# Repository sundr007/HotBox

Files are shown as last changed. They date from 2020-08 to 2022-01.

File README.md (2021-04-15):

# HotBox


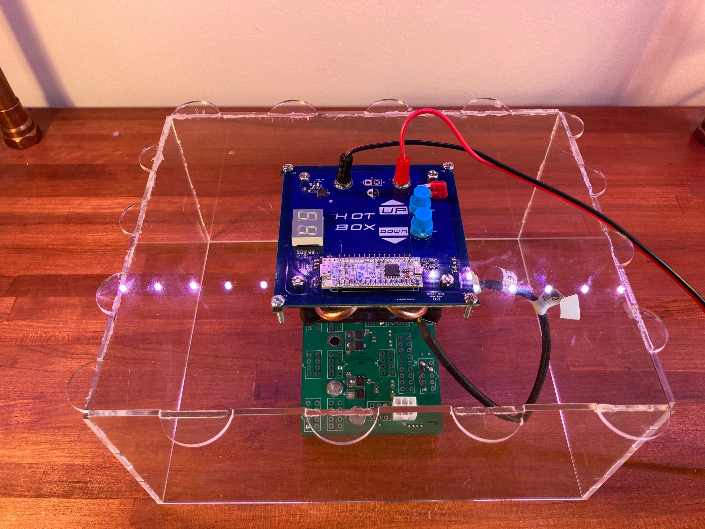
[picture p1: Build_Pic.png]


I use this when I'm testing electronics on my benchtop.  I put this box on top of what I'm testing to raise the ambient temperature.  This is convenient because I can leave my probes and other wires hooked up as is.
This box can raise the ambient temperature up to 55C.

The design consists of a finger edge laser cut acrylic box that has a circuit board assembly mount in the top center of it.  I put foam on the bottom edge of the box so it can nicely sit on top of wires and cables without air gaps.  

The circuit board assembly consists of a 2 layer PCB meant to fit PCBWAY's cheap board special (hint,they're $1 a piece for QTY 5).  On the PCB there is a ST NUCLEO-G431KB board which is an easy way to add a microcontroller.  There's 2 buttons to control temperature setpoint, a 7 segment display to display temperature, a peltier plate that acts as the heating element, and an Intel LGA1155 processor fan to spread the heat from the peltier plate.

I have built the current revision and found that it works as expected and I'm able to use it as I debug and test my electronics.

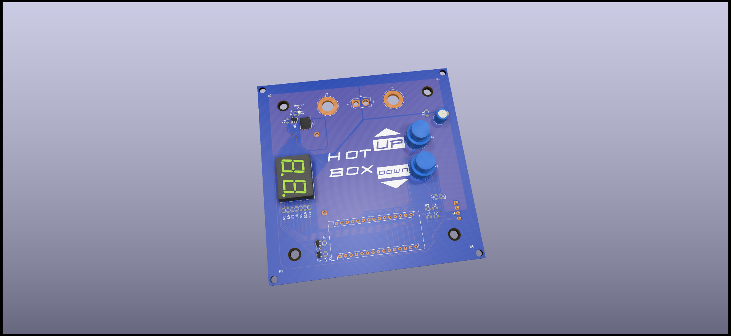
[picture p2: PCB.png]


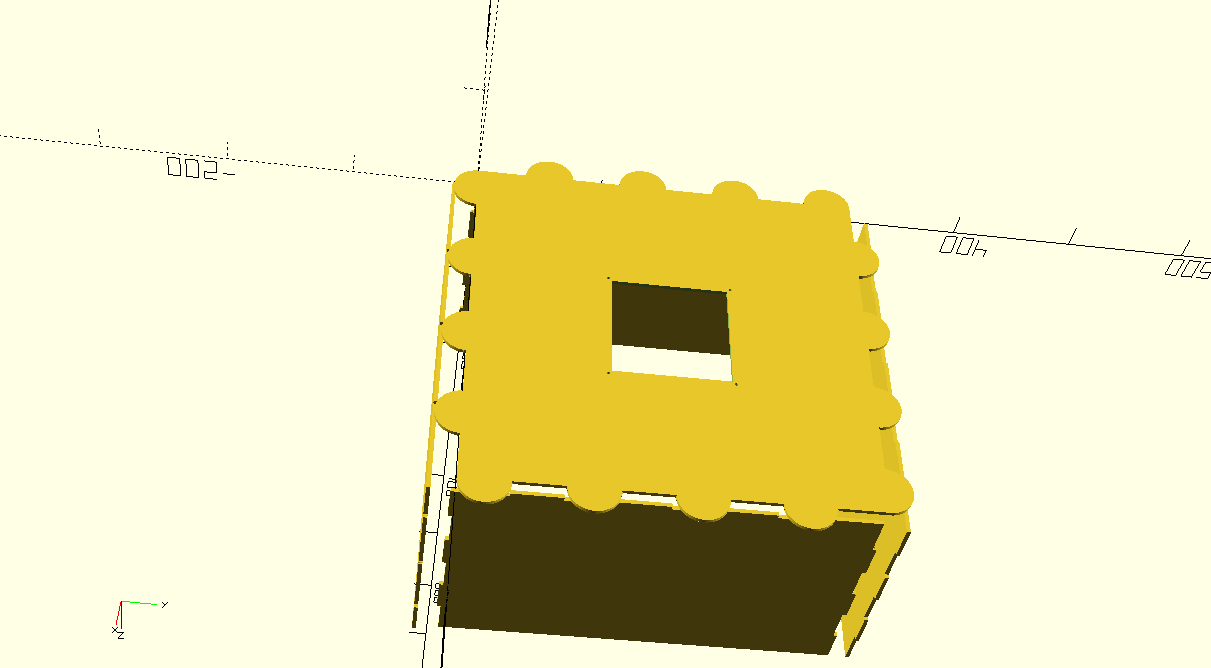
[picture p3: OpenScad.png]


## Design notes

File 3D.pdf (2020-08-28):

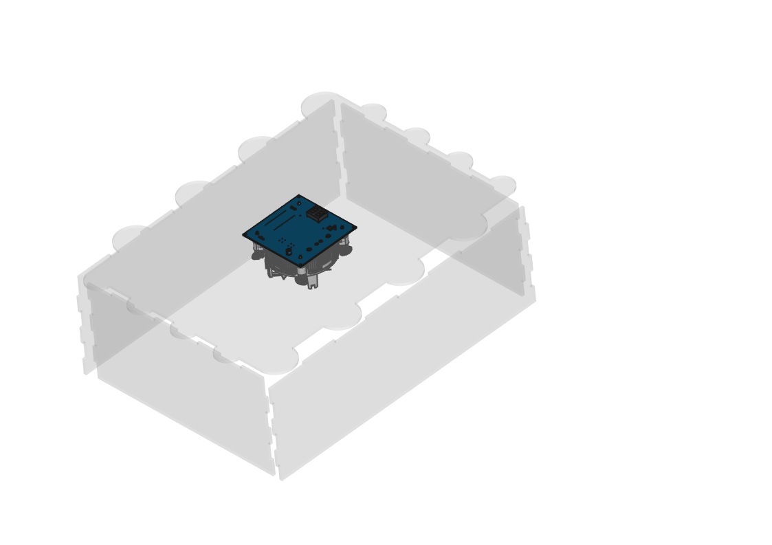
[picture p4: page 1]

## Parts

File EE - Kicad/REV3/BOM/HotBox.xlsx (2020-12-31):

Prj: | HotBox.xml |  |  |  | Board Qty: | 100
Co.: |  |  |  |  | Unit Cost: | $0.00
Prj date: | Mon 23 Nov 2020 11:21:40 PM CST |  |  |  | Total Cost: | $0.00 |  |  |  | $0.00 | 0 |  |  |  | $0.00 | 0 |  |  |  | $0.00 | 0 |  |  |  | $0.00 | 0 |  |  |  | $0.00 | 0 |  |  |  | $0.00 | 0 |  |  |  | $0.00 | 0 |  |  |  | $0.00 | 0
$ date: | 2020-11-23 23:21:47
Global Part Info |  |  |  |  |  |  | Arrow |  |  |  |  | Digi-Key |  |  |  |  | Farnell |  |  |  |  | LCSC |  |  |  |  | Mouser |  |  |  |  | Newark |  |  |  |  | RS Components |  |  |  |  | TME
Refs | Value | Footprint | Manf# | Qty | Unit$ | Ext$ | Avail | Purch | Unit$ | Ext$ | Cat# | Avail | Purch | Unit$ | Ext$ | Cat# | Avail | Purch | Unit$ | Ext$ | Cat# | Avail | Purch | Unit$ | Ext$ | Cat# | Avail | Purch | Unit$ | Ext$ | Cat# | Avail | Purch | Unit$ | Ext$ | Cat# | Avail | Purch | Unit$ | Ext$ | Cat# | Avail | Purch | Unit$ | Ext$ | Cat#
A1 | Arduino_Nano_v3.x | Arduino_Nano | NUCLEO-G431KB (http://www.mouser.com/pdfdocs/Gravitech_Arduino_Nano3_0.pdf) | 0 | $0.00 | $0.00 |  |  |  |  |  | 190 |  | $0.00 | $0.00 | 497-19489-ND (https://octopart.com/click/track?ai=8078&sig=0ef4511&sid=459&ppid=102284322&vpid=549854330&ct=offers) | 125 |  | $0.00 | $0.00 | 3132398 (https://octopart.com/click/track?ai=8078&sig=0c02d9d&sid=819&ppid=102284322&vpid=551646278&ct=offers) |  |  |  |  |  | 222 |  | $0.00 | $0.00 | 511NUCLEOG431KB (https://octopart.com/click/track?ai=8078&sig=01da76f&sid=2401&ppid=102284322&vpid=551367201&ct=offers) | NonStk |  | $0.00 | $0.00 | 17AH9213 (https://octopart.com/click/track?c=1&ai=8078&sig=0658d93&sid=2402&ppid=102284322&vpid=573252533&ct=offers) | 56 |  | $0.00 | $0.00 | 1962534 (https://octopart.com/click/track?ai=8078&sig=00e1ef2&sid=10022&ppid=102284322&vpid=625435198&ct=offers)
C4 | 10uF | CP_Radial_D6.3mm_P2.50mm | RS81C101MDN1 | 0 | $0.00 | $0.00 |  |  |  |  |  | 917 |  | $0.00 | $0.00 | 493-16595-ND (https://octopart.com/click/track?c=1&ai=8078&sig=039926a&sid=459&ppid=50011049&vpid=475684332&ct=offers) |  |  |  |  |  |  |  |  |  |  | 105 |  | $0.00 | $0.00 | 647RS81C101MDN1 (https://octopart.com/click/track?ai=8078&sig=066d4c4&sid=2401&ppid=50011049&vpid=269048423&ct=offers)
C1-C3,C5 | 0.1uF | 0805_C | 08055D104KAT2A | 0 | $0.00 | $0.00 |  |  |  |  |  | 18121 |  | $0.00 | $0.00 | 478-12790-1-ND (https://octopart.com/click/track?ai=8078&sig=05fcdeb&sid=459&ppid=2169154&vpid=531908010&ct=offers) |  |  |  |  |  |  |  |  |  |  | 4236 |  | $0.00 | $0.00 | 58108055D104K (https://octopart.com/click/track?ai=8078&sig=057f866&sid=2401&ppid=2169154&vpid=37768389&ct=offers) | NonStk |  | $0.00 | $0.00 | 55J7638 (https://octopart.com/click/track?c=1&ai=8078&sig=0eeb785&sid=2402&ppid=2169154&vpid=13274115&ct=offers)
D1 | LED | LED_0603_1608Metric | 150060RS75000 | 0 | $0.00 | $0.00 |  |  |  |  |  | 142218 |  | $0.00 | $0.00 | 732-4978-1-ND (https://octopart.com/click/track?ai=8078&sig=02853a2&sid=459&ppid=29717776&vpid=91297449&ct=offers) | 16113 |  | $0.00 | $0.00 | 2322071 (https://octopart.com/click/track?ai=8078&sig=068ebbc&sid=11744&ppid=29717776&vpid=132755220&ct=offers) |  |  |  |  |  | 55821 |  | $0.00 | $0.00 | 710150060RS75000 (https://octopart.com/click/track?ai=8078&sig=0c69a59&sid=2401&ppid=29717776&vpid=165625624&ct=offers) | 10 |  | $0.00 | $0.00 | 95W3795 (https://octopart.com/click/track?ai=8078&sig=0b01e3f&sid=2402&ppid=29717776&vpid=82629805&ct=offers) | 7100 |  | $0.00 | $0.00 | 8154203 (https://octopart.com/click/track?ai=8078&sig=0abbfde&sid=10022&ppid=29717776&vpid=199194534&ct=offers)
D2 | D | D_SMA | MURA230T3G | 0 | $0.00 | $0.00 |  |  |  |  |  | 5443 |  | $0.00 | $0.00 | MURA230T3GOSCT-ND (https://octopart.com/click/track?ai=8078&sig=0de4a30&sid=459&ppid=332360&vpid=52500538&ct=offers) | 3850 |  | $0.00 | $0.00 | 2844708 (https://octopart.com/click/track?ai=8078&sig=070358e&sid=819&ppid=332360&vpid=503458609&ct=offers) | 15080 |  | $0.00 | $0.00 | C242411 (https://octopart.com/click/track?ai=8078&sig=036f2bd&sid=27971&ppid=332360&vpid=486581120&ct=offers) | 11578 |  | $0.00 | $0.00 | 863MURA230T3G (https://octopart.com/click/track?ai=8078&sig=067908d&sid=2401&ppid=332360&vpid=458432707&ct=offers) | 5000 |  | $0.00 | $0.00 | 50AC6160 (https://octopart.com/click/track?c=1&ai=8078&sig=072d2b2&sid=2402&ppid=332360&vpid=504110550&ct=offers)
H1-H4 | MountingHole | MountingHole_3.2mm_M3 | RM3X6MM 2701 | 0 | $0.00 | $0.00 |  |  |  |  |  | 12111 |  | $0.00 | $0.00 | 335-1156-ND (https://octopart.com/click/track?c=1&ai=8078&sig=004c205&sid=459&ppid=55603181&vpid=187954207&ct=offers) |  |  |  |  |  |  |  |  |  |  |  |  |  |  |  | NonStk |  |  |  | 02J6475 (https://octopart.com/click/track?c=1&ai=8078&sig=024b449&sid=2402&ppid=55603181&vpid=227885963&ct=offers)
J1 | Conn_01x02 | AMASS_XT30U-M_1x02_P5.0mm_Vertical |  | 0 | $0.00 | $0.00
J2,J3 | Conn_01x01 | Banana_Jack_1Pin | 575-4 | 0 | $0.00 | $0.00 |  |  |  |  |  | 42940 |  | $0.00 | $0.00 | 36-575-4-ND (https://octopart.com/click/track?ai=8078&sig=0e57466&sid=459&ppid=225184&vpid=212428255&ct=offers) | 3681 |  | $0.00 | $0.00 | 3366825 (https://octopart.com/click/track?ai=8078&sig=0d89cbe&sid=11744&ppid=225184&vpid=607742724&ct=offers) |  |  |  |  |  | 12541 |  | $0.00 | $0.00 | 5345754 (https://octopart.com/click/track?ai=8078&sig=0824e70&sid=2401&ppid=225184&vpid=37679473&ct=offers) | 3681 |  | $0.00 | $0.00 | 99H8227 (https://octopart.com/click/track?ai=8078&sig=08ce9e0&sid=2402&ppid=225184&vpid=96235925&ct=offers)
M1 | Fan_4pin | FanPinHeader_1x04_P2.54mm_Vertical | PREC004SAAN-RC (http://www.formfactors.org/developer%5Cspecs%5Crev1_2_public.pdf) | 0 | $0.00 | $0.00 |  |  |  |  |  | 4435 |  | $0.00 | $0.00 | S1012EC-04-ND (https://octopart.com/click/track?c=1&ai=8078&sig=06a6967&sid=459&ppid=22265093&vpid=47550066&ct=offers)
M2 | Fan | LGA1155_FAN |  | 0 | $0.00 | $0.00
PE1 | Peltier_Element | Peltier_40x40 |  | 0 | $0.00 | $0.00
Q1 | BSC028N06LS3 | TDSON-8-1 | PSMN9R1-30YL,115 | 0 | $0.00 | $0.00 |  |  |  |  |  | 1863 |  | $0.00 | $0.00 | 1727-5435-1-ND (https://octopart.com/click/track?ai=8078&sig=0e99631&sid=459&ppid=78741898&vpid=417207430&ct=offers) | 1480 |  | $0.00 | $0.00 | 3440124 (https://octopart.com/click/track?ai=8078&sig=0647d91&sid=819&ppid=78741898&vpid=623939668&ct=offers) |  |  |  |  |  | 2893 |  | $0.00 | $0.00 | 771PSMN9R130YL115 (https://octopart.com/click/track?ai=8078&sig=09e2a15&sid=2401&ppid=78741898&vpid=458423102&ct=offers) | NonStk |  | $0.00 | $0.00 | 74AH1210 (https://octopart.com/click/track?c=1&ai=8078&sig=0a8d3df&sid=2402&ppid=78741898&vpid=625406500&ct=offers)
Q2 | PUMB11,115 | SOT-363_SC-70-6_Handsoldering | PUMB11,115 (http://datasheet.octopart.com/PUMB11%2C115-Nexperia-datasheet-86559598.pdf) | 0 | $0.00 | $0.00 |  |  |  |  |  | 22810 |  | $0.00 | $0.00 | 1727-5230-1-ND (https://octopart.com/click/track?ai=8078&sig=0827af8&sid=459&ppid=78742000&vpid=417207844&ct=offers) | 3925 |  | $0.00 | $0.00 | 8738190 (https://octopart.com/click/track?ai=8078&sig=0dd91fb&sid=11744&ppid=78742000&vpid=531931792&ct=offers) |  |  |  |  |  | 13393 |  | $0.00 | $0.00 | 771PUMB11T/R (https://octopart.com/click/track?ai=8078&sig=0140538&sid=2401&ppid=78742000&vpid=416182520&ct=offers) | NonStk |  | $0.00 | $0.00 | 92K8274 (https://octopart.com/click/track?c=1&ai=8078&sig=0a87b09&sid=2402&ppid=78742000&vpid=532391430&ct=offers)
Q4 | PUMD3,115 | SOT-363_SC-70-6_Handsoldering | PUMD3,165 (http://datasheet.octopart.com/PUMD3%2C165-Nexperia-datasheet-115885228.pdf) | 0 | $0.00 | $0.00 |  |  |  |  |  | 9307 |  | $0.00 | $0.00 | 1727-1984-1-ND (https://octopart.com/click/track?ai=8078&sig=084be59&sid=459&ppid=78742011&vpid=417207879&ct=offers)
R14,R15 | 10k | 0805_R | CRCW080510K0JNEAC | 0 | $0.00 | $0.00 |  |  |  |  |  | 54515 |  | $0.00 | $0.00 | 541-4163-1-ND (https://octopart.com/click/track?ai=8078&sig=0e3dded&sid=459&ppid=22248114&vpid=454353709&ct=offers) |  |  |  |  |  |  |  |  |  |  | 258423 |  | $0.00 | $0.00 | 71CRCW080510K0JNEAC (https://octopart.com/click/track?ai=8078&sig=0e7bfa5&sid=2401&ppid=22248114&vpid=458953937&ct=offers) | NonStk |  |  |  | 98AC1023 (https://octopart.com/click/track?c=1&ai=8078&sig=00685fc&sid=2402&ppid=22248114&vpid=634340854&ct=offers)
R2,R4 | 10K | 0805_R | CRCW080510K0JNEAC | 0 | $0.00 | $0.00 |  |  |  |  |  | 54515 |  | $0.00 | $0.00 | 541-4163-1-ND (https://octopart.com/click/track?ai=8078&sig=0e3dded&sid=459&ppid=22248114&vpid=454353709&ct=offers) |  |  |  |  |  |  |  |  |  |  | 258423 |  | $0.00 | $0.00 | 71CRCW080510K0JNEAC (https://octopart.com/click/track?ai=8078&sig=0e7bfa5&sid=2401&ppid=22248114&vpid=458953937&ct=offers) | NonStk |  |  |  | 98AC1023 (https://octopart.com/click/track?c=1&ai=8078&sig=00685fc&sid=2402&ppid=22248114&vpid=634340854&ct=offers)
RN1,RN2 | 510 | R_Array_Convex_4x0603 | YC164-JR-07510RL | 0 | $0.00 | $0.00 |  |  |  |  |  | 18466 |  | $0.00 | $0.00 | YC164J-510CT-ND (https://octopart.com/click/track?ai=8078&sig=0bb4886&sid=459&ppid=1242880&vpid=1344494&ct=offers) |  |  |  |  |  |  |  |  |  |  | 12242 |  | $0.00 | $0.00 | 603YC164JR07510RL (https://octopart.com/click/track?ai=8078&sig=04d159e&sid=2401&ppid=1242880&vpid=213198410&ct=offers)
SW1,SW2 | SW_Push_4PIN | SW_D6 | D6R60 F2 LFS | 0 | $0.00 | $0.00 |  |  |  |  |  | 1854 |  | $0.00 | $0.00 | 401-1994-ND (https://octopart.com/click/track?ai=8078&sig=0d235d0&sid=459&ppid=7881546&vpid=196134140&ct=offers) |  |  |  |  |  |  |  |  |  |  | 637 |  | $0.00 | $0.00 | 611D6R60F2LFS (https://octopart.com/click/track?ai=8078&sig=094bb8d&sid=2401&ppid=7881546&vpid=37851280&ct=offers) | NonStk |  | $0.00 | $0.00 | 34AH9183 (https://octopart.com/click/track?c=1&ai=8078&sig=0a176ba&sid=2402&ppid=7881546&vpid=587918301&ct=offers)
TH1,TH2 | Thermistor_NTC | 0805_R | NTCG203NH103JT1 | 0 | $0.00 | $0.00 |  |  |  |  |  | 2049 |  | $0.00 | $0.00 | 445-175460-1-ND (https://octopart.com/click/track?ai=8078&sig=02080f6&sid=459&ppid=59351339&vpid=467517010&ct=offers) | 1710 |  | $0.00 | $0.00 | 3407730 (https://octopart.com/click/track?ai=8078&sig=05cd269&sid=11744&ppid=59351339&vpid=627120507&ct=offers) |  |  |  |  |  | 484 |  | $0.00 | $0.00 | 810NTCG203NH103JT1 (https://octopart.com/click/track?ai=8078&sig=0193e37&sid=2401&ppid=59351339&vpid=261797022&ct=offers) | NonStk |  | $0.00 | $0.00 | 69AH9056 (https://octopart.com/click/track?c=1&ai=8078&sig=05de465&sid=2402&ppid=59351339&vpid=620880923&ct=offers)
U1 | UA78M33CDCYR | SOT-223-3_TabPin2 | UA78M33CDCYR | 0 | $0.00 | $0.00 |  |  |  |  |  | 23359 |  | $0.00 | $0.00 | 296-13424-1-ND (https://octopart.com/click/track?ai=8078&sig=0d57e92&sid=459&ppid=525280&vpid=1569654&ct=offers) | 25000 |  | $0.00 | $0.00 | 2102683 (https://octopart.com/click/track?ai=8078&sig=0f6c954&sid=11744&ppid=525280&vpid=474713883&ct=offers) | 10181 |  | $0.00 | $0.00 | C49036 (https://octopart.com/click/track?ai=8078&sig=0b19de3&sid=27971&ppid=525280&vpid=454624488&ct=offers) | 14439 |  | $0.00 | $0.00 | 595UA78M33CDCYR (https://octopart.com/click/track?ai=8078&sig=033990e&sid=2401&ppid=525280&vpid=37849384&ct=offers) | 5546 |  | $0.00 | $0.00 | 33AH5474 (https://octopart.com/click/track?c=1&ai=8078&sig=03fc223&sid=2402&ppid=525280&vpid=585374083&ct=offers)
U2 | DA04-11CGKWA | DA04-11CGKWA | LDD-A402NI | 0 | $0.00 | $0.00 |  |  |  |  |  | NonStk |  | $0.00 | $0.00 | 67-1419-ND (https://octopart.com/click/track?c=1&ai=8078&sig=01d729b&sid=459&ppid=548500&vpid=1721458&ct=offers)
 | Used currency rates: |  |  |  | Total Purchase: | $0.00 |  | 0 |  | $0.00 |  |  | 0 |  | $0.00 |  |  | 0 |  | $0.00 |  |  | 0 |  | $0.00 |  |  | 0 |  | $0.00 |  |  | 0 |  | $0.00 |  |  | 0 |  | $0.00 |  |  | 0 |  | $0.00
 | USD($)/GBP(£): | 1.293904701 |  |  | Purchase description: |  |  | 0 |  |  |  |  | 0 |  |  |  |  | 0 |  |  |  |  | 0 |  |  |  |  | 0 |  |  |  |  | 0 |  |  |  |  | 0 |  |  |  |  | 0
 |  |  |  |  |  |  |  | 0 |  |  |  |  | 0 |  |  |  |  | 0 |  |  |  |  | 0 |  |  |  |  | 0 |  |  |  |  | 0 |  |  |  |  | 0 |  |  |  |  | 0
KiCost® v.1.1.4 |  |  |  |  |  |  |  | 0 |  |  |  |  | 0 |  |  |  |  | 0 |  |  |  |  | 0 |  |  |  |  | 0 |  |  |  |  | 0 |  |  |  |  | 0 |  |  |  |  | 0
 |  |  |  |  |  |  |  | 0 |  |  |  |  | 0 |  |  |  |  | 0 |  |  |  |  | 0 |  |  |  |  | 0 |  |  |  |  | 0 |  |  |  |  | 0 |  |  |  |  | 0
 |  |  |  |  |  |  |  | 0 |  |  |  |  | 0 |  |  |  |  | 0 |  |  |  |  | 0 |  |  |  |  | 0 |  |  |  |  | 0 |  |  |  |  | 0 |  |  |  |  | 0
 |  |  |  |  |  |  |  | 0 |  |  |  |  | 0 |  |  |  |  | 0 |  |  |  |  | 0 |  |  |  |  | 0 |  |  |  |  | 0 |  |  |  |  | 0 |  |  |  |  | 0
 |  |  |  |  |  |  |  | 0 |  |  |  |  | 0 |  |  |  |  | 0 |  |  |  |  | 0 |  |  |  |  | 0 |  |  |  |  | 0 |  |  |  |  | 0 |  |  |  |  | 0
 |  |  |  |  |  |  |  | 0 |  |  |  |  | 0 |  |  |  |  | 0 |  |  |  |  | 0 |  |  |  |  | 0 |  |  |  |  | 0 |  |  |  |  | 0 |  |  |  |  | 0
 |  |  |  |  |  |  |  | 0 |  |  |  |  | 0 |  |  |  |  | 0 |  |  |  |  | 0 |  |  |  |  | 0 |  |  |  |  | 0 |  |  |  |  | 0 |  |  |  |  | 0
 |  |  |  |  |  |  |  | 0 |  |  |  |  | 0 |  |  |  |  | 0 |  |  |  |  | 0 |  |  |  |  | 0 |  |  |  |  | 0 |  |  |  |  | 0 |  |  |  |  | 0
 |  |  |  |  |  |  |  | 0 |  |  |  |  | 0 |  |  |  |  | 0 |  |  |  |  | 0 |  |  |  |  | 0 |  |  |  |  | 0 |  |  |  |  | 0 |  |  |  |  | 0
 |  |  |  |  |  |  |  | 0 |  |  |  |  | 0 |  |  |  |  | 0 |  |  |  |  | 0 |  |  |  |  | 0 |  |  |  |  | 0 |  |  |  |  | 0 |  |  |  |  | 0
 |  |  |  |  |  |  |  | 0 |  |  |  |  | 0 |  |  |  |  | 0 |  |  |  |  | 0 |  |  |  |  | 0 |  |  |  |  | 0 |  |  |  |  | 0 |  |  |  |  | 0
 |  |  |  |  |  |  |  | 0 |  |  |  |  | 0 |  |  |  |  | 0 |  |  |  |  | 0 |  |  |  |  | 0 |  |  |  |  | 0 |  |  |  |  | 0 |  |  |  |  | 0
 |  |  |  |  |  |  |  | 0 |  |  |  |  | 0 |  |  |  |  | 0 |  |  |  |  | 0 |  |  |  |  | 0 |  |  |  |  | 0 |  |  |  |  | 0 |  |  |  |  | 0
 |  |  |  |  |  |  |  | 0 |  |  |  |  | 0 |  |  |  |  | 0 |  |  |  |  | 0 |  |  |  |  | 0 |  |  |  |  | 0 |  |  |  |  | 0 |  |  |  |  | 0
 |  |  |  |  |  |  |  | 0 |  |  |  |  | 0 |  |  |  |  | 0 |  |  |  |  | 0 |  |  |  |  | 0 |  |  |  |  | 0 |  |  |  |  | 0 |  |  |  |  | 0
 |  |  |  |  |  |  |  | 0 |  |  |  |  | 0 |  |  |  |  | 0 |  |  |  |  | 0 |  |  |  |  | 0 |  |  |  |  | 0 |  |  |  |  | 0 |  |  |  |  | 0
 |  |  |  |  |  |  |  | 0 |  |  |  |  | 0 |  |  |  |  | 0 |  |  |  |  | 0 |  |  |  |  | 0 |  |  |  |  | 0 |  |  |  |  | 0 |  |  |  |  | 0
 |  |  |  |  |  |  |  | 0 |  |  |  |  | 0 |  |  |  |  | 0 |  |  |  |  | 0 |  |  |  |  | 0 |  |  |  |  | 0 |  |  |  |  | 0 |  |  |  |  | 0
 |  |  |  |  |  |  |  | 0 |  |  |  |  | 0 |  |  |  |  | 0 |  |  |  |  | 0 |  |  |  |  | 0 |  |  |  |  | 0 |  |  |  |  | 0 |  |  |  |  | 0
 |  |  |  |  |  |  |  |  |  |  |  |  |  |  |  |  |  |  |  |  |  |  | 0

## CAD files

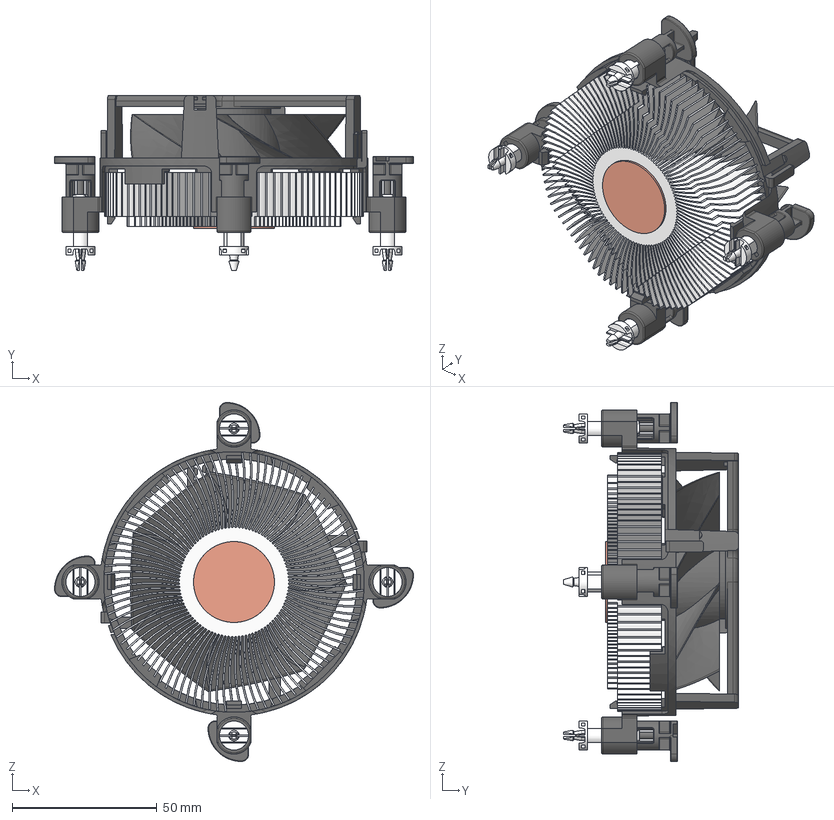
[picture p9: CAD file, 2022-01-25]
EE - Kicad/REV3/Intel Stock LGA 1155 Cooler Assembly.stp
123.9 x 60.5 x 123.9 mm
Heatsink
Fan Mount
Push Clip x 4
Pin x 4

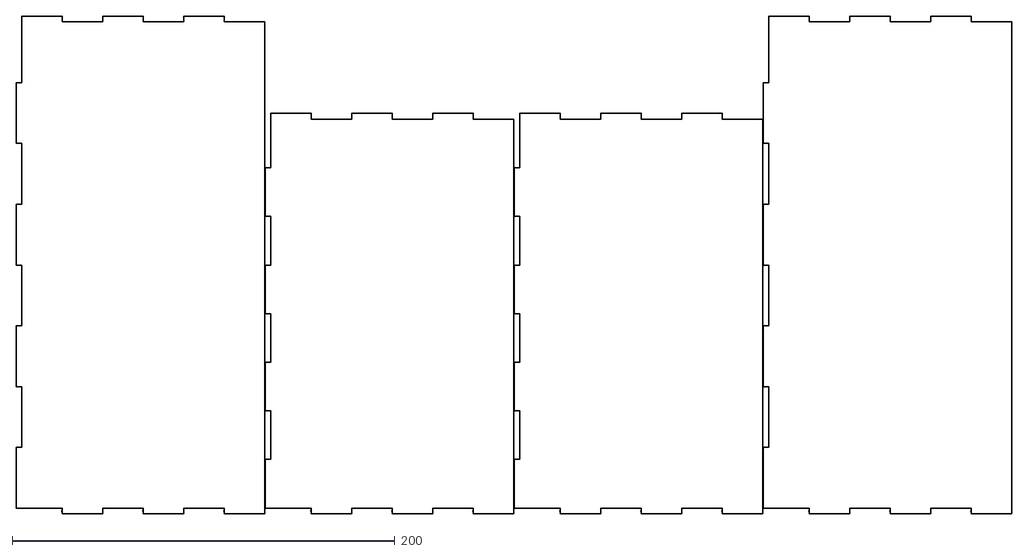
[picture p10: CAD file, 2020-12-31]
Build/ME/sides.dxf
520.3 x 260.0

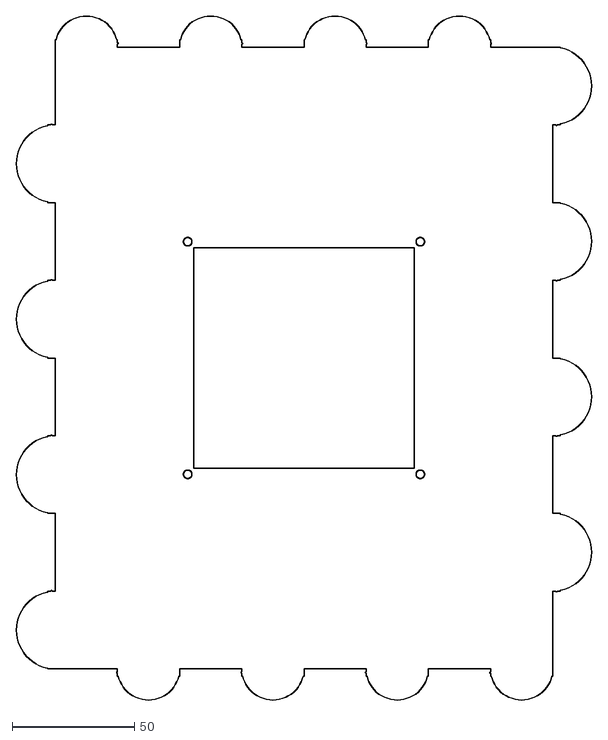
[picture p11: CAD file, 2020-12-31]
Build/ME/top.dxf
235.0 x 279.4

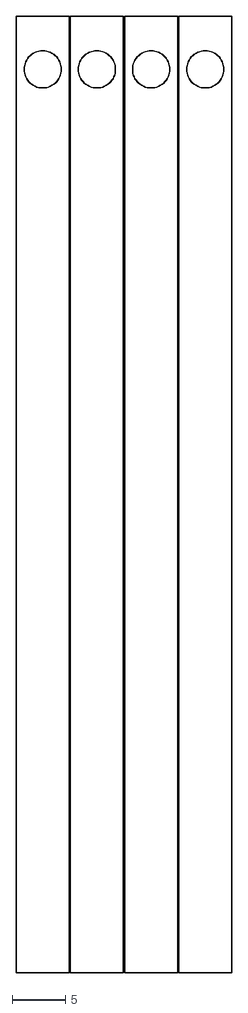
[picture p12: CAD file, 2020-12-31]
Build/ME/Gasket.dxf
20.3 x 90.0

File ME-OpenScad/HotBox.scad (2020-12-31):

include </home/evan/Documents/github/lasercut/lasercut.scad>; 

use<projection_renderer.scad>;
use<label.scad>;

$fn=60;
// ##### RENDERING OPTIONS #####

render_3d   = false;
//2D
render_sides       = false;
render_top         = false;
render_gasket      = true;

// ##### Dimensions #####
x_in= 8;
y_in= 10;
z_in= 5;
// #####  #####

thickness = 3;
x   = x_in*25.4;
y   = y_in*25.4;
z   = z_in*25.4;
// PCB Size
x_pcb = 100;
y_pcb = 100;
// Intel Fan
HoleSize=3.5/2;
x_f = 95;
y_f = x_f;
// Cutout size
x_c = 90;
y_c = x_c;
// fingers
NfSide=3;
NfTop=4;
// Fan connector cutout
FconnL=12;
FconnP=8;
FconnDepth=5;

module side(x,y)
{
    lasercutoutSquare(thickness=thickness, x=x, y=y,
    bumpy_finger_joints=[
            [DOWN, 1, NfSide]
        ],
    finger_joints=[
            [LEFT, 1, NfTop],
            [UP,1,NfSide]
        ]
    );
}

module enclosure_bottom_etch() {
    color("red") 
    linear_extrude(height=2, center=true) {
            text_label(["Hot","Box"],20);
    }
 
    translate([100,0,0]){
    color("red") 
    linear_extrude(height=2, center=true) {
            text_label([str(x_in,"x",y_in,"x",z_in),
                        "EDS",
                       ],10);
    }
}
}

module top()
{
      lasercutoutSquare(thickness=thickness, x=x, y=y,
    bumpy_finger_joints=[
            [UP, 1, NfTop],
            [DOWN, 1, NfTop],
            [RIGHT, 1, NfTop],
            [LEFT, 1, NfTop]
        ],
    cutouts = [
            [x/2-x_c/2, y/2-y_c/2, x_c, y_c], // Main Cutout
            //[x/2-x_c/2-FconnDepth, y/2+y_c/2-FconnL-FconnP, FconnDepth, FconnL]  // Fan Connector
        ],
    circles_remove = [
            [HoleSize, x/2+x_f/2, y/2+y_f/2],
            [HoleSize, x/2+x_f/2, y/2-y_f/2],
            [HoleSize, x/2-x_f/2, y/2+y_f/2],
            [HoleSize, x/2-x_f/2, y/2-y_f/2],
        ]
    );
  for(off = [x/(NfTop*2*2) : x/NfTop : x]){
      translate([off,y,0])
        cylinder(r=x/(NfTop*2*2),h=thickness);
      translate([off+x/(NfTop*2),0,0])
        cylinder(r=x/(NfTop*2*2),h=thickness);
  }
  for(off = [y/(NfTop*2*2) : y/NfTop : y]){
      translate([0,off,0])
        cylinder(r=y/(NfTop*2*2),h=thickness);
      translate([x,off+y/(NfTop*2),0])
        cylinder(r=y/(NfTop*2*2),h=thickness);
  }  
  //translate([x/1,y/10,0]) mirror([1,0,0])
   // enclosure_bottom_etch();
}

module gasket(){
        linear_extrude(1){
            difference(){
                square([(x_pcb-x_c)/2,y_pcb-(y_pcb-y_c)],center=true);
                translate([0,y_c/2-(x_pcb-x_c)/2,0]) circle(HoleSize);      
            }
        }
}
module gasket_set(){
    shift = (x_pcb-x_c)/2;
    translate([x_c/2,shift,0])gasket();
    translate([0,0,0])gasket();
    translate([0,0,0])gasket();
    translate([0,0,0])gasket();
}


module 3d() {
// Print the sides
    side(z,y);
translate([0,y+3.5,thickness]) rotate([90,0,0]) 
    side(z,x); 
translate([0,-3.5,thickness+x]) rotate([-90,0,0]) 
    side(z,x); 
translate([0,y,thickness+x+3.5]) rotate([180,0,0]) 
    side(z,y); 

// Print the top
translate([-3.5,0,x+3.5]) rotate([0,90,0])
    top();
  translate([-3.5-1,y/2,x/2]) rotate([0,90,0])
    gasket_set();  
    
}

module laser_etch() {
    if (render_etch || render_index == -1) {
        children();
    }
}

if (render_3d) {
        rotate([90,90,0])
            3d();
} else {
    kerf=0.1;
   // projection_renderer(render_index=render_index, kerf_width//=0.1) {  
  projection(){
    if(render_sides){  
            side(z,y);
        translate([z+thickness+.1, 0, 0]) 
            side(z,x);
        translate([(z+thickness+.1)*2, 0, 0]) 
            side(z,x);
        translate([(z+thickness+.1)*3, 0, 0])  
            side(z,y);
    }
    if(render_top){
        //translate([(y+thickness+80)*2, 0, 0]) 
            top();
          //  translate([(y+thickness+80)*2, 0, 0]) 
            //    mirror([0,0,0])
              //  enclosure_bottom_etch();
    }
    if(render_gasket){
        for(ix=[0:3])
            translate([ix*((x_pcb-x_c)/2+kerf),0,0])
                gasket();
    }
}
}

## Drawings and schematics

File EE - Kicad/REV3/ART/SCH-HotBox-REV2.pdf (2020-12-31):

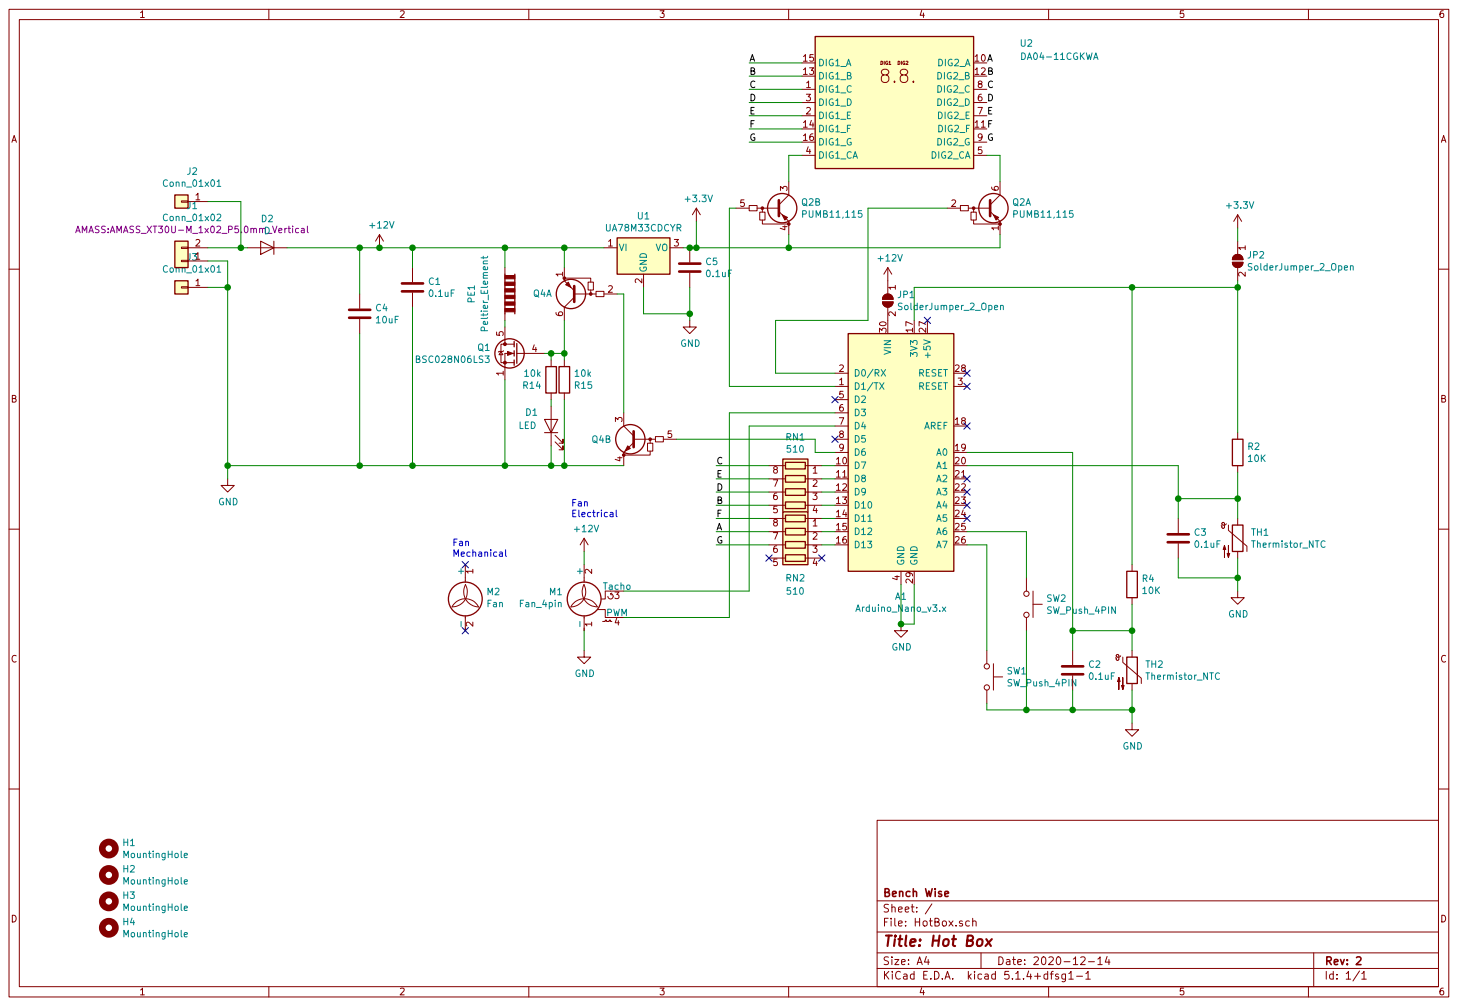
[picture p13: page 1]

Fan Electrical Fan Mechanical

File: HotBox.sch Sheet: / Bench Wise

Id: 1/1 Title: Hot Box

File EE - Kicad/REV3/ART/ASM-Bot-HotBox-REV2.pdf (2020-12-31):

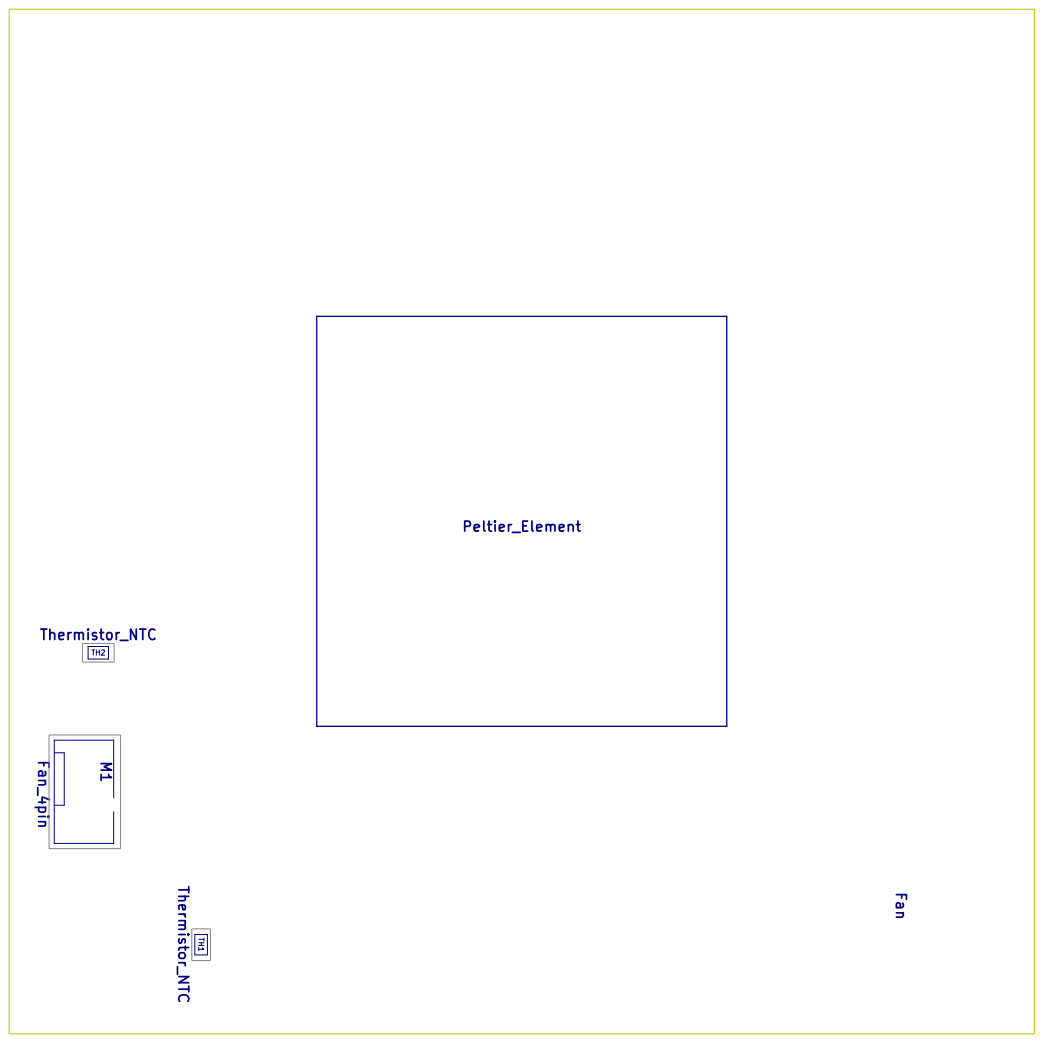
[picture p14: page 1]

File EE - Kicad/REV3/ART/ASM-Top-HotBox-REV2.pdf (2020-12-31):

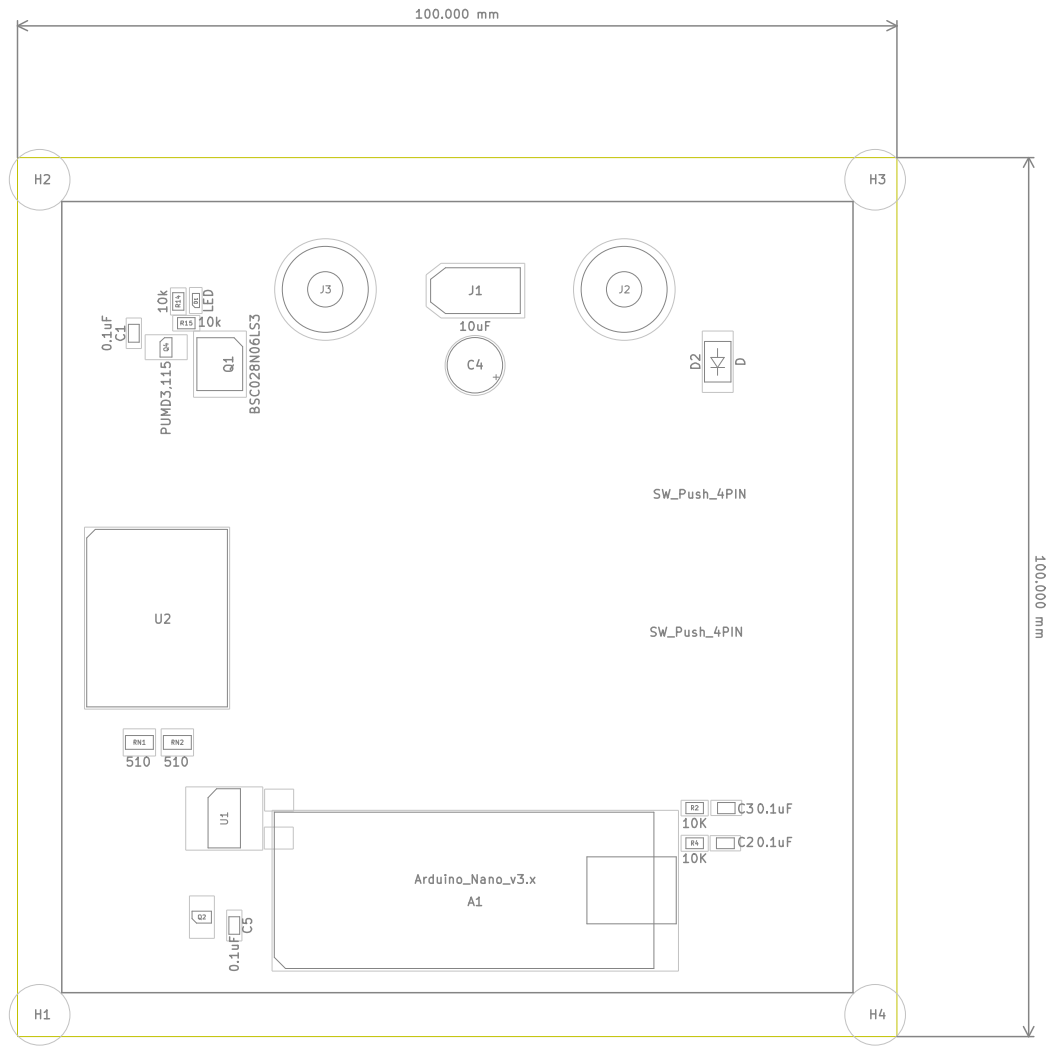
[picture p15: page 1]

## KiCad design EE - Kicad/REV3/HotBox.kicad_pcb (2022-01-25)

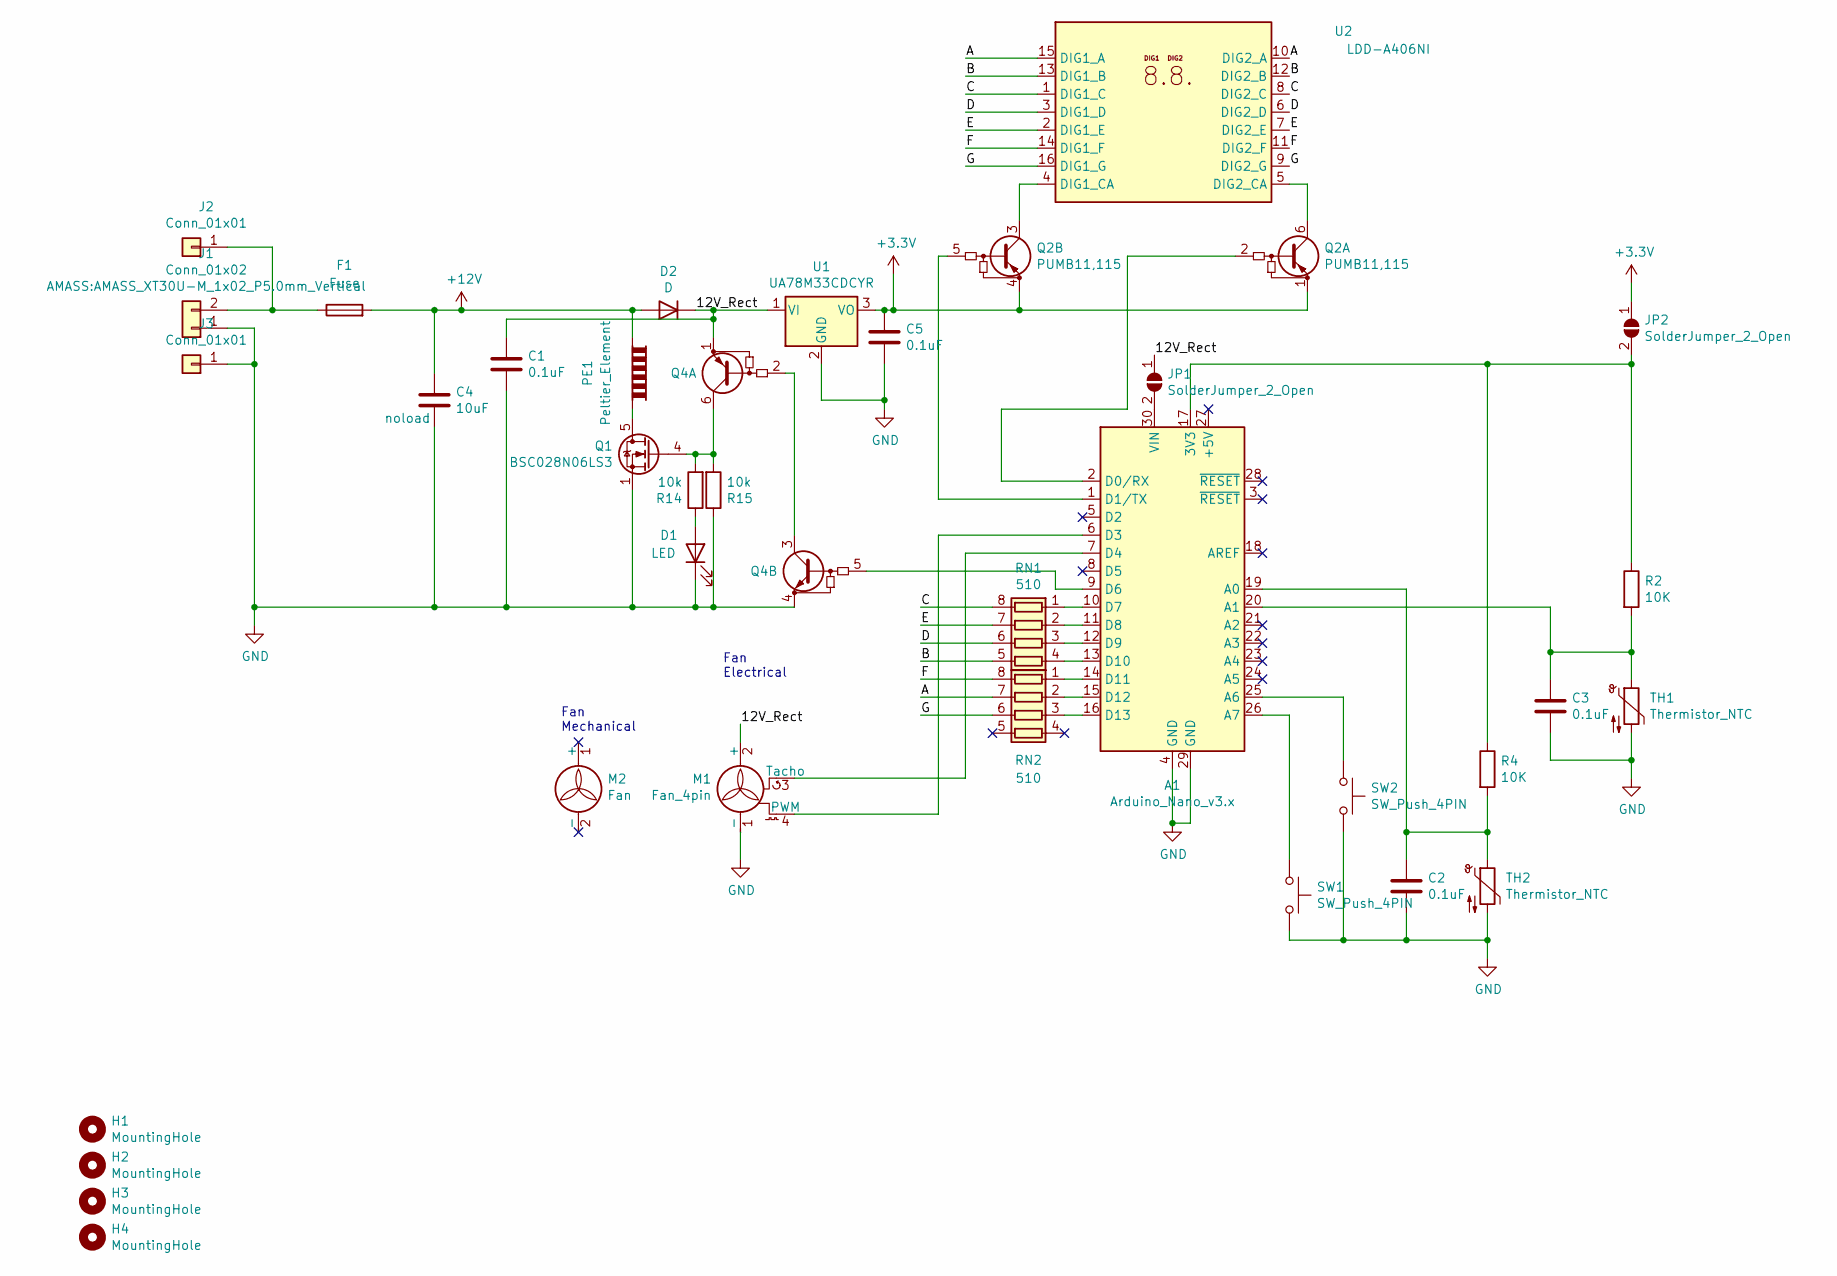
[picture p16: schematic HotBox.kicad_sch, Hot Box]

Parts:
A1: Arduino_Nano_v3.x; Arduino_Nano; DigikeyPN 497-19489-ND
C1, C2, C3, C5: 0.1uF; 0805_C; DigikeyPN 478-12790-1-ND
C4: 10uF; CP_Radial_D6.3mm_P2.50mm; DigikeyPN 493-16595-ND
D1: LED; LED_0603_1608Metric; DigikeyPN 732-4978-1-ND
D2: D; D_SMA; DigikeyPN SS13-LTPMSCT-ND
F1: Fuse; R_1206_3216Metric; DigikeyPN SF-1206HH10M-2CT-ND
H1, H2, H3, H4: MountingHole; MountingHole_3.2mm_M3; DigikeyPN 335-1156-ND
J1: Conn_01x02; AMASS_XT30U-M_1x02_P5.0mm_Vertical; DigikeyPN Amass XT30
J2, J3: Conn_01x01; Banana_Jack_1Pin; DigikeyPN 36-575-4-ND
JP1, JP2: SolderJumper_2_Open; SolderJumper-2_P1.3mm_Open_TrianglePad1.0x1.5mm
M1: Fan_4pin; FanPinHeader_1x04_P2.54mm_Vertical; DigikeyPN S1012EC-04-ND
M2: Fan; LGA1155_FAN; DigikeyPN Intel E98290-001
PE1: Peltier_Element; Peltier_40x40; DigikeyPN TEC1-12706
Q1: BSC028N06LS3; TDSON-8-1; DigikeyPN 1727-5435-1-ND
Q2: PUMB11,115; SOT-363_SC-70-6_Handsoldering; DigikeyPN 1727-5230-1-ND
Q4: PUMD3,115; SOT-363_SC-70-6_Handsoldering; DigikeyPN 1727-1984-1-ND
R2, R4: 10K; 0805_R; DigikeyPN 541-4163-1-ND
R14, R15: 10k; 0805_R; DigikeyPN 541-4163-1-ND
RN1, RN2: 510; R_Array_Convex_4x0603; DigikeyPN YC164J-510CT-ND
SW1, SW2: SW_Push_4PIN; SW_D6; DigikeyPN 401-1994-ND
TH1: Thermistor_NTC; 0805_R; DigikeyPN 445-175460-1-ND
TH2: Thermistor_NTC; SolderWire-0.25sqmm_1x02_P4.2mm_D0.65mm_OD1.7mm; DigikeyPN 445-175460-1-ND
U1: UA78M33CDCYR; SOT-223-3_TabPin2; DigikeyPN 296-13424-1-ND
U2: LDD-A406NI; DA04-11CGKWA; DigikeyPN 67-1447-ND

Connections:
+3V3: C5.1, JP2.1 (A), Q2.1 (E1), Q2.4 (E2), U1.3 (VO)
+12V: C4.1, D2.2 (A), F1.2, PE1.1
/12V_Rect: C1.1, D2.1 (K), JP1.1 (A), M1.2 (+), Q4.1 (E1), U1.1 (VI)
/A: RN2.7 (R2.2), U2.10 (DIG2_A), U2.15 (DIG1_A)
/B: RN1.5 (R4.2), U2.12 (DIG2_B), U2.13 (DIG1_B)
/C: RN1.8 (R1.2), U2.1 (DIG1_C), U2.8 (DIG2_C)
/D: RN1.6 (R3.2), U2.3 (DIG1_D), U2.6 (DIG2_D)
/E: RN1.7 (R2.2), U2.2 (DIG1_E), U2.7 (DIG2_E)
/F: RN2.8 (R1.2), U2.11 (DIG2_F), U2.14 (DIG1_F)
/G: RN2.6 (R3.2), U2.9 (DIG2_G), U2.16 (DIG1_G)
GND: A1.4 (GND), A1.29 (GND), C1.2, C2.2, C3.2, C4.2, C5.2, D1.1 (K), J1.1, J3.1, M1.1 (-), Q1.1 (S), Q1.2 (S), Q1.3 (S), Q4.4 (E1), R15.1, SW1.2, SW2.2, TH1.2, TH2.2, U1.2 (GND)
unnamed: A1.1 (D1/TX), Q2.5 (B2)
unnamed: A1.2 (D0/RX), Q2.2 (B1)
unnamed: A1.6 (D3), M1.4 (PWM)
unnamed: A1.7 (D4), M1.3 (Tacho)
unnamed: A1.9 (D6), Q4.5 (B1)
unnamed: A1.10 (D7), RN1.1 (R1.1)
unnamed: A1.11 (D8), RN1.2 (R2.1)
unnamed: A1.12 (D9), RN1.3 (R3.1)
unnamed: A1.13 (D10), RN1.4 (R4.1)
unnamed: A1.14 (D11), RN2.1 (R1.1)
unnamed: A1.15 (D12), RN2.2 (R2.1)
unnamed: A1.16 (D13), RN2.3 (R3.1)
unnamed: A1.17 (3V3), JP2.2 (B), R2.1, R4.1
unnamed: A1.19 (A0), C2.1, R4.2, TH2.1
unnamed: A1.20 (A1), C3.1, R2.2, TH1.1
unnamed: A1.25 (A6), SW2.1
unnamed: A1.26 (A7), SW1.1
unnamed: A1.30 (VIN), JP1.2 (B)
unnamed: D1.2 (A), R14.1
unnamed: F1.1, J1.2, J2.1
unnamed: PE1.2, Q1.5 (D)
unnamed: Q1.4 (G), Q4.6 (C1), R14.2, R15.2
unnamed: Q2.3 (C2), U2.4 (DIG1_CA)
unnamed: Q2.6 (C1), U2.5 (DIG2_CA)
unnamed: Q4.2 (B1), Q4.3 (C1)

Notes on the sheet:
Fan Mechanical
Fan Electrical

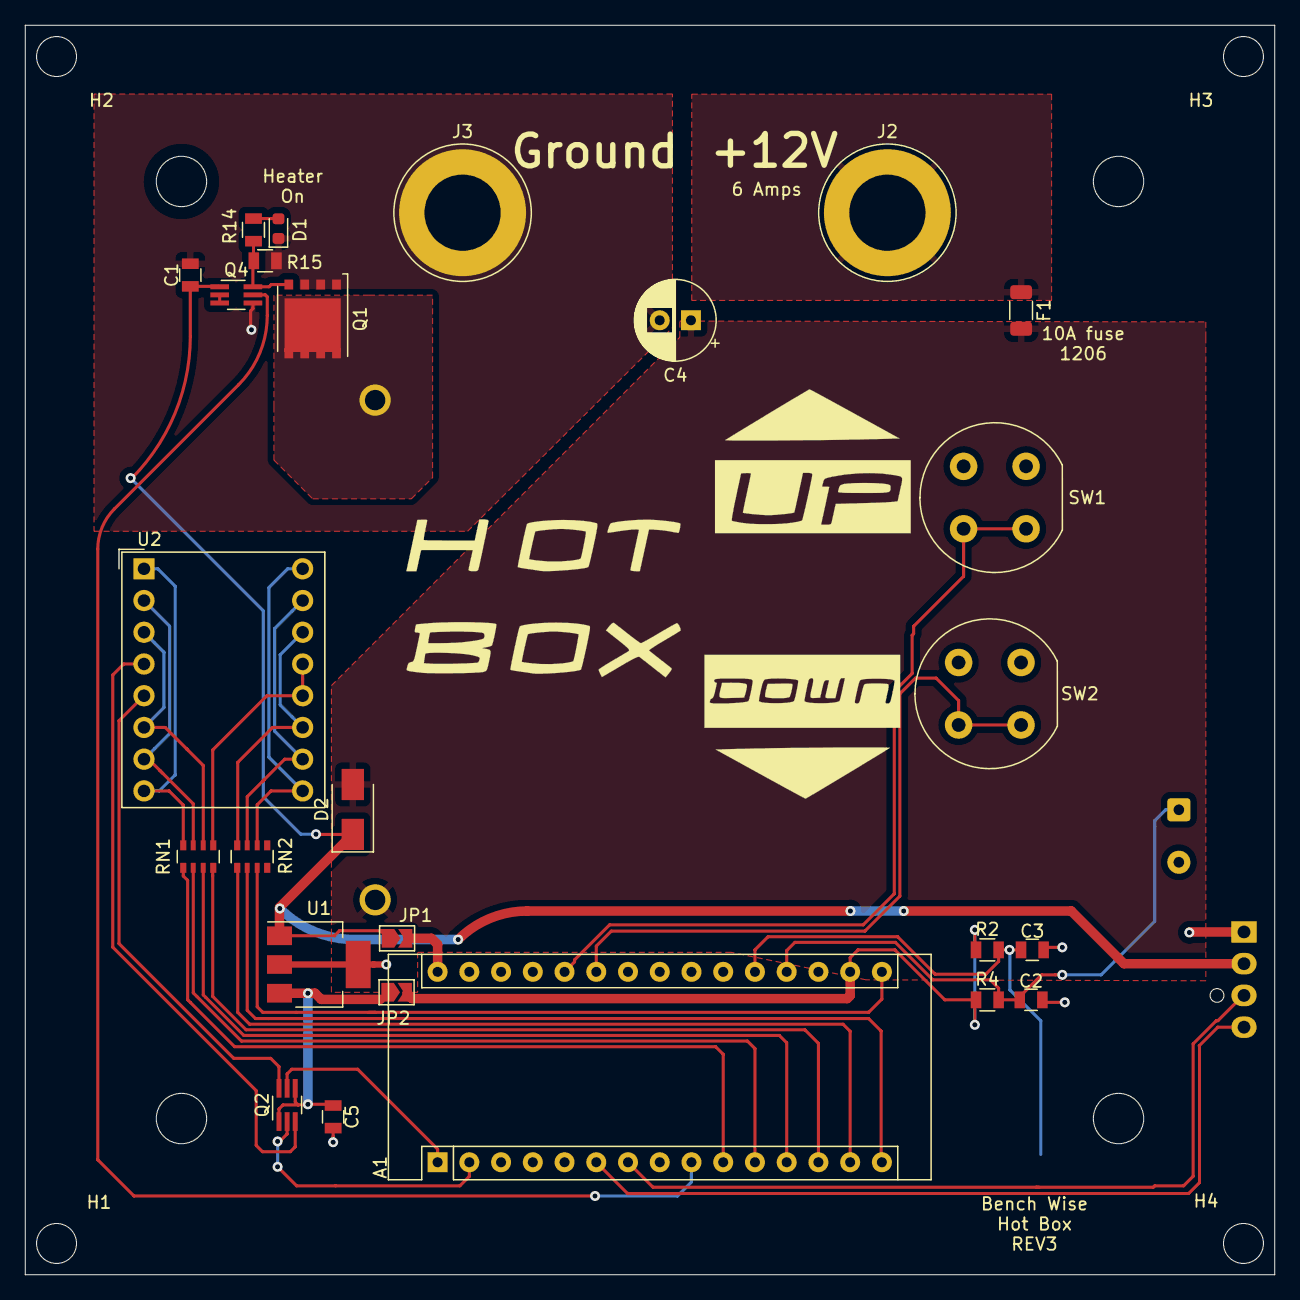
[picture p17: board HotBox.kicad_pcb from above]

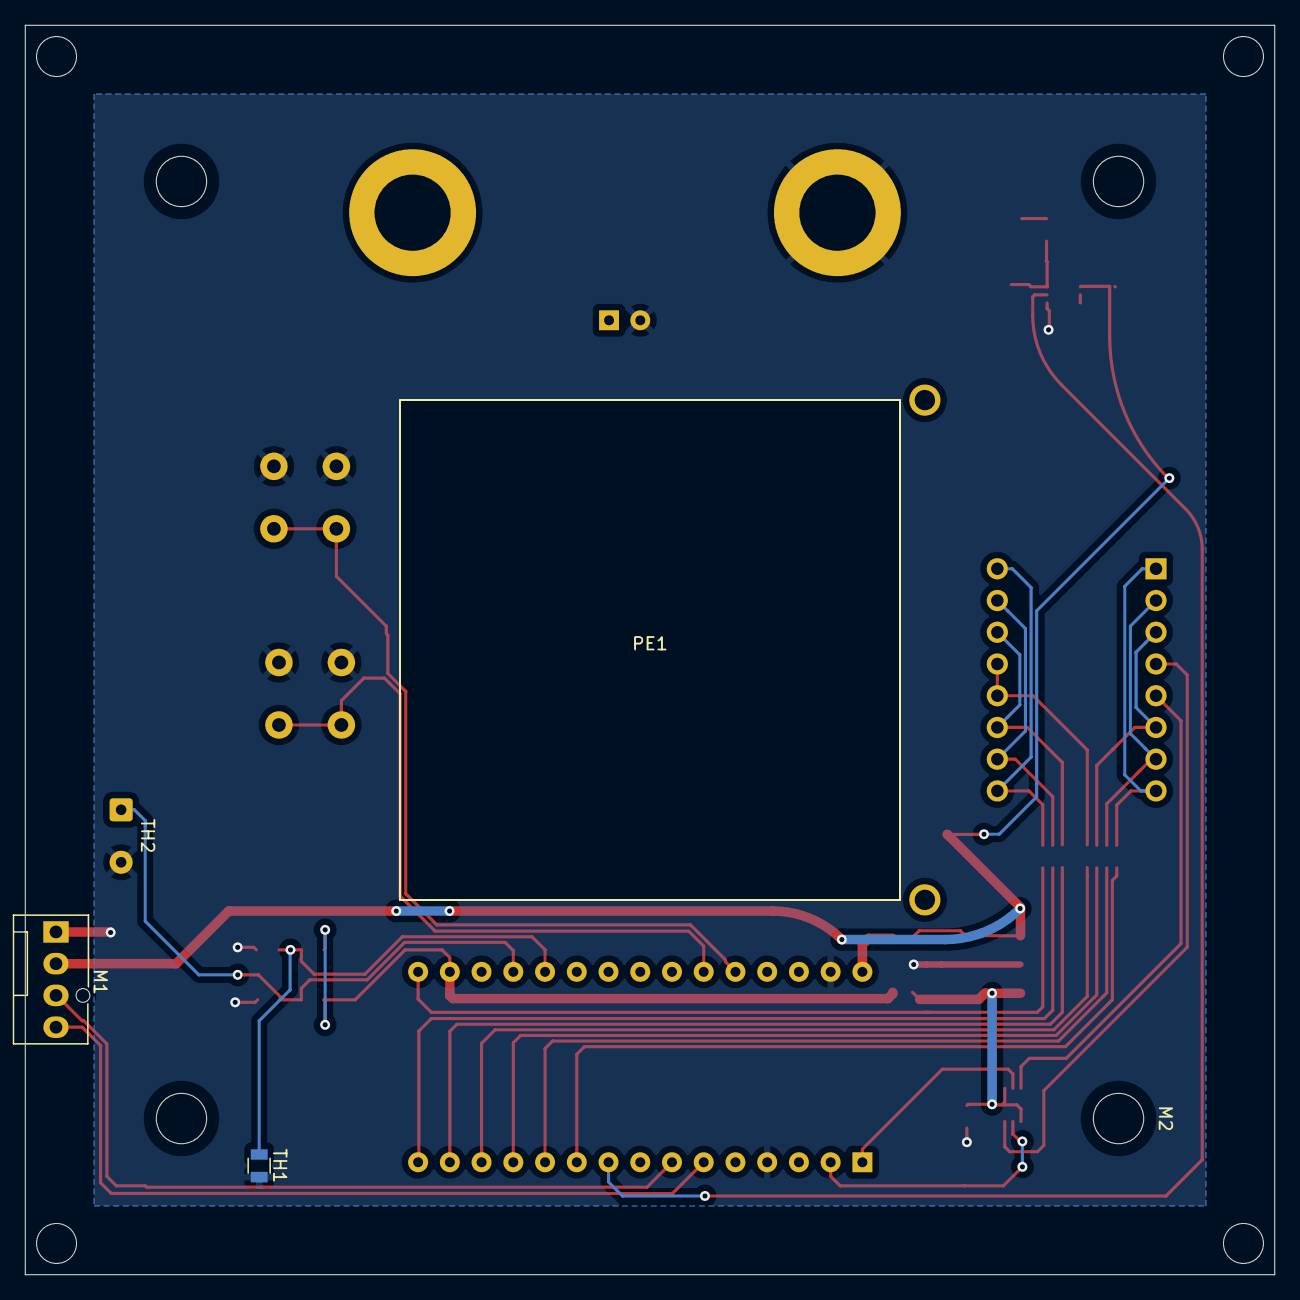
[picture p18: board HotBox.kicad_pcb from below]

Board: 2 copper layers, 100.0 x 100.0 mm, 35 parts (5 on the bottom side), 36 nets.

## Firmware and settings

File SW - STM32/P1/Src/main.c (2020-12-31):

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

/* Includes ------------------------------------------------------------------*/
#include "main.h"
#include "cmsis_os.h"

/* USER CODE BEGIN Includes */
#include "SEVEN_SEGMENTS.h"
#include "TempSense.h"
/* USER CODE END Includes */

/* USER CODE BEGIN PM */
#define Setpoin_MIN		10
#define Setpoin_MAX		70


#define TURN_LED_ON 	HAL_GPIO_WritePin(LD2_GPIO_Port, LD2_Pin, GPIO_PIN_SET)
#define TURN_LED_OFF 	HAL_GPIO_WritePin(LD2_GPIO_Port, LD2_Pin, GPIO_PIN_RESET)

#define TURN_HEATER_ON 	HAL_GPIO_WritePin(Heater_EN_GPIO_Port, Heater_EN_Pin, GPIO_PIN_SET)
#define TURN_HEATER_OFF HAL_GPIO_WritePin(Heater_EN_GPIO_Port, Heater_EN_Pin, GPIO_PIN_RESET)

#define A(on) 			( on ? HAL_GPIO_WritePin(A_GPIO_Port, A_Pin, GPIO_PIN_RESET) : HAL_GPIO_WritePin(A_GPIO_Port, A_Pin, GPIO_PIN_SET))
#define B(on) 			( on ? HAL_GPIO_WritePin(B_GPIO_Port, B_Pin, GPIO_PIN_RESET) : HAL_GPIO_WritePin(B_GPIO_Port, B_Pin, GPIO_PIN_SET))
#define C(on) 			( on ? HAL_GPIO_WritePin(C_GPIO_Port, C_Pin, GPIO_PIN_RESET) : HAL_GPIO_WritePin(C_GPIO_Port, C_Pin, GPIO_PIN_SET))
#define D(on) 			( on ? HAL_GPIO_WritePin(D_GPIO_Port, D_Pin, GPIO_PIN_RESET) : HAL_GPIO_WritePin(D_GPIO_Port, D_Pin, GPIO_PIN_SET))
#define E(on) 			( on ? HAL_GPIO_WritePin(E_GPIO_Port, E_Pin, GPIO_PIN_RESET) : HAL_GPIO_WritePin(E_GPIO_Port, E_Pin, GPIO_PIN_SET))
#define F(on) 			( on ? HAL_GPIO_WritePin(F_GPIO_Port, F_Pin, GPIO_PIN_RESET) : HAL_GPIO_WritePin(F_GPIO_Port, F_Pin, GPIO_PIN_SET))
#define G(on) 			( on ? HAL_GPIO_WritePin(G_GPIO_Port, G_Pin, GPIO_PIN_RESET) : HAL_GPIO_WritePin(G_GPIO_Port, G_Pin, GPIO_PIN_SET))

#define one				A(0);B(0);C(0);D(0);E(1);F(1);G(0)
#define two				A(1);B(1);C(0);D(1);E(1);F(0);G(1)
#define three			A(1);B(0);C(0);D(1);E(1);F(1);G(1)
#define four			A(0);B(0);C(1);D(0);E(1);F(1);G(1)
#define five			A(1);B(0);C(1);D(1);E(0);F(1);G(1)
#define six				A(1);B(1);C(1);D(1);E(0);F(1);G(1)
#define seven			A(0);B(0);C(0);D(1);E(1);F(1);G(0)
#define eight			A(1);B(1);C(1);D(1);E(1);F(1);G(1)
#define nine			A(0);B(0);C(1);D(1);E(1);F(1);G(1)

/* USER CODE END PM */

ADC_HandleTypeDef hadc1;

TIM_HandleTypeDef htim3;

/* Definitions for blink01 */
osThreadId_t blink01Handle;
const osThreadAttr_t blink01_attributes = {
  .name = "blink01",
  .priority = (osPriority_t) osPriorityNormal,
  .stack_size = 128 * 4
};
/* Definitions for blink02 */
osThreadId_t blink02Handle;
const osThreadAttr_t blink02_attributes = {
  .name = "blink02",
  .priority = (osPriority_t) osPriorityBelowNormal,
  .stack_size = 128 * 4
};
void SystemClock_Config(void);
static void MX_GPIO_Init(void);
static void MX_ADC1_Init(void);
static void MX_TIM3_Init(void);
void Startblink01(void *argument);
void Startblink02(void *argument);

/* USER CODE BEGIN PFP */
static void setPWM(TIM_HandleTypeDef, uint32_t, uint16_t, uint16_t);
/* USER CODE END PFP */

/**
  * @brief  The application entry point.
  * @retval int
  */
int main(void)
{
  /* MCU Configuration--------------------------------------------------------*/

  /* Reset of all peripherals, Initializes the Flash interface and the Systick. */
  HAL_Init();

  /* Configure the system clock */
  SystemClock_Config();

  /* Initialize all configured peripherals */
  MX_GPIO_Init();
  MX_ADC1_Init();
  MX_TIM3_Init();
  /* USER CODE BEGIN 2 */
  SEVEN_SEG_Init(0);
  SEVEN_SEG_Enable(0);
  SEVEN_SEG_Write(0, 0);

  __HAL_RCC_TIM3_CLK_ENABLE();

//  HAL_TIM_Base_Start(&htim3);
  HAL_TIM_PWM_Start(&htim3,TIM_CHANNEL_ALL);
  /* USER CODE END 2 */

  /* Init scheduler */
  osKernelInitialize();

  /* USER CODE BEGIN RTOS_MUTEX */
  /* add mutexes, ... */
  /* USER CODE END RTOS_MUTEX */

  /* USER CODE BEGIN RTOS_SEMAPHORES */
  /* add semaphores, ... */
  /* USER CODE END RTOS_SEMAPHORES */

  /* USER CODE BEGIN RTOS_TIMERS */
  /* start timers, add new ones, ... */
  /* USER CODE END RTOS_TIMERS */

  /* USER CODE BEGIN RTOS_QUEUES */
  /* add queues, ... */
  /* USER CODE END RTOS_QUEUES */

  /* Create the thread(s) */
  /* creation of blink01 */
  blink01Handle = osThreadNew(Startblink01, NULL, &blink01_attributes);

  /* creation of blink02 */
  blink02Handle = osThreadNew(Startblink02, NULL, &blink02_attributes);

  /* USER CODE BEGIN RTOS_THREADS */
  /* add threads, ... */
  /* USER CODE END RTOS_THREADS */

  /* Start scheduler */
  osKernelStart();
 
  /* We should never get here as control is now taken by the scheduler */
  /* Infinite loop */
  /* USER CODE BEGIN WHILE */
  HAL_ADC_Start(&hadc1);

  while (1)
  {
    /* USER CODE END WHILE */

    /* USER CODE BEGIN 3 */
  }
  /* USER CODE END 3 */
}

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
/* USER CODE BEGIN 4 */
void user_pwm_setvalue(uint16_t value)
{
    TIM_OC_InitTypeDef sConfigOC;

    sConfigOC.OCMode = TIM_OCMODE_PWM1;
    sConfigOC.Pulse = value;
    sConfigOC.OCPolarity = TIM_OCPOLARITY_HIGH;
    sConfigOC.OCFastMode = TIM_OCFAST_DISABLE;
    HAL_TIM_PWM_ConfigChannel(&htim3, &sConfigOC, TIM_CHANNEL_3);
    HAL_TIM_PWM_Start(&htim3, TIM_CHANNEL_3);
}

void setPWM(TIM_HandleTypeDef timer, uint32_t channel, uint16_t period,
uint16_t pulse)
{
HAL_TIM_PWM_Stop(&timer, channel);
// stop generation of pwm
TIM_OC_InitTypeDef sConfigOC;
timer.Init.Period = period;
// set the period duration
HAL_TIM_PWM_Init(&timer); // reinititialise with new period value
sConfigOC.OCMode = TIM_OCMODE_PWM1;
sConfigOC.Pulse = pulse;
// set the pulse duration
sConfigOC.OCPolarity = TIM_OCPOLARITY_HIGH;
sConfigOC.OCFastMode = TIM_OCFAST_DISABLE;
HAL_TIM_PWM_ConfigChannel(&timer, &sConfigOC, channel);
HAL_TIM_PWM_Start(&timer, channel);
}
/* USER CODE END 4 */

/* USER CODE BEGIN Header_Startblink01 */
/**
  * @brief  Function implementing the blink01 thread.
  * @param  argument: Not used 
  * @retval None
  */
/* USER CODE END Header_Startblink01 */
void Startblink01(void *argument)
{
  /* USER CODE BEGIN 5 */
	static uint16_t setpoint;
	static uint16_t blocked;
  /* Infinite loop */
  setpoint = 25;
  blocked = 0;
  for(;;)
  {

	  uint32_t ADCValue;

		uint32_t SW_Down = HAL_GPIO_ReadPin(SW_DOWN_GPIO_Port,SW_DOWN_Pin);
		if (!SW_Down && (setpoint > Setpoin_MIN)){
			setpoint--;
			blocked = 40;
			SEVEN_SEG_Write(0, setpoint);
		}
		vTaskDelay( 50 / portTICK_PERIOD_MS );
		uint32_t SW_Up = HAL_GPIO_ReadPin(SW_UP_GPIO_Port,SW_UP_Pin);
		if (!SW_Up && (setpoint < Setpoin_MAX)){
			setpoint++;
			blocked = 40;
			SEVEN_SEG_Write(0, setpoint);
		}
		if (blocked==0){
			HAL_ADC_Start(&hadc1);
	      if (HAL_ADC_PollForConversion(&hadc1, 1000000) == HAL_OK)
	      {
	    	  ADCValue = HAL_ADC_GetValue(&hadc1);
	    	  uint16_t temp	= (uint16_t) (readThermistor(ADCValue)+0.5);
	    	  SEVEN_SEG_Write(0, temp);
	    	  if(temp < setpoint){
	    		  TURN_HEATER_ON;
	    		  setPWM(htim3, TIM_CHANNEL_3, 4095, 4095);
	    	  }
	    	  else if(temp > (setpoint+1)){
	    		  TURN_HEATER_OFF;
	    		  setPWM(htim3, TIM_CHANNEL_3, 4095, 2000);
	    	  }
	      }
		}
		else{
			blocked--;
		}
		vTaskDelay( 50 / portTICK_PERIOD_MS );
//		for (uint16_t i = 1; i < 100; i++) {
//			SEVEN_SEG_Write(0, i);
//			vTaskDelay( 400 / portTICK_PERIOD_MS );
//		}
  }
  /* USER CODE END 5 */ 
}

/* USER CODE BEGIN Header_Startblink02 */
/**
* @brief Function implementing the blink02 thread.
* @param argument: Not used
* @retval None
*/
/* USER CODE END Header_Startblink02 */
void Startblink02(void *argument)
{
  /* USER CODE BEGIN Startblink02 */
  /* Infinite loop */
  for(;;)
  {
	  vTaskDelay( 5 / portTICK_PERIOD_MS );
      SEVEN_SEG_Main();
  }
  /* USER CODE END Startblink02 */
}

 /**
  * @brief  Period elapsed callback in non blocking mode
  * @note   This function is called  when TIM6 interrupt took place, inside
  * HAL_TIM_IRQHandler(). It makes a direct call to HAL_IncTick() to increment
  * a global variable "uwTick" used as application time base.
  * @param  htim : TIM handle
  * @retval None
  */
void HAL_TIM_PeriodElapsedCallback(TIM_HandleTypeDef *htim)
{
  if (htim->Instance == TIM6) {
    HAL_IncTick();
  }
}

/**
  * @brief  This function is executed in case of error occurrence.
  * @retval None
  */
void Error_Handler(void)
{
  /* USER CODE BEGIN Error_Handler_Debug */
  /* User can add his own implementation to report the HAL error return state */

  /* USER CODE END Error_Handler_Debug */
}

#ifdef  USE_FULL_ASSERT
/**
  * @brief  Reports the name of the source file and the source line number
  *         where the assert_param error has occurred.
  * @param  file: pointer to the source file name
  * @param  line: assert_param error line source number
  * @retval None
  */
void assert_failed(uint8_t *file, uint32_t line)
{ 
  /* USER CODE BEGIN 6 */
  /* User can add his own implementation to report the file name and line number,
     tex: printf("Wrong parameters value: file %s on line %d\r\n", file, line) */
  /* USER CODE END 6 */
}
#endif /* USE_FULL_ASSERT */

/************************ (C) COPYRIGHT STMicroelectronics *****END OF FILE****/

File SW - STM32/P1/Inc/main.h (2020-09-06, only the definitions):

#define C_Pin GPIO_PIN_0
#define C_GPIO_Port GPIOF
#define E_Pin GPIO_PIN_1
#define E_GPIO_Port GPIOF
#define Thermistor2_Pin GPIO_PIN_0
#define Thermistor2_GPIO_Port GPIOA
#define SW_UP_Pin GPIO_PIN_2
#define SW_UP_GPIO_Port GPIOA
#define SW_DOWN_Pin GPIO_PIN_7
#define SW_DOWN_GPIO_Port GPIOA
#define FAN_PWM_Pin GPIO_PIN_0
#define FAN_PWM_GPIO_Port GPIOB
#define D_Pin GPIO_PIN_8
#define D_GPIO_Port GPIOA
#define DIG1_CA_Pin GPIO_PIN_9
#define DIG1_CA_GPIO_Port GPIOA
#define DIG2_CA_Pin GPIO_PIN_10
#define DIG2_CA_GPIO_Port GPIOA
#define B_Pin GPIO_PIN_11
#define B_GPIO_Port GPIOA
#define T_SWDIO_Pin GPIO_PIN_13
#define T_SWDIO_GPIO_Port GPIOA
#define T_SWCLK_Pin GPIO_PIN_14
#define T_SWCLK_GPIO_Port GPIOA
#define G_Pin GPIO_PIN_3
#define G_GPIO_Port GPIOB
#define A_Pin GPIO_PIN_4
#define A_GPIO_Port GPIOB
#define F_Pin GPIO_PIN_5
#define F_GPIO_Port GPIOB
#define Heater_EN_Pin GPIO_PIN_6
#define Heater_EN_GPIO_Port GPIOB
#define LD2_Pin GPIO_PIN_8
#define LD2_GPIO_Port GPIOB

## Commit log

2020-08-28 Initial Commit of design files. STM32 SW place holder added.
    [HotBox-B_Cu.gbl, HotBox-B_Mask.gbs, HotBox-B_Paste.gbp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]
2020-08-28 Add PCB image for MD file.
2020-09-06 Add SW Init
    [P1 Debug (1).cfg, P1 Debug.cfg]
2020-09-06 Added Fan PWM Functionality
2020-09-08 Fixed a temperature readback bug. The bug is likely a HW bug, but was fixed by reducing the ADC clock frequency. Because of the low cost nature of the design this is acceptable. Also added floating p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
    [New_configuration.cfg]
2020-09-13 Added limits to the temperature setpoint. Slowed the processor clock to reduce power draw.
2020-09-13 Seperated the EE into orderable REVs. Created REV2 based on things that didn't work well in REV1.
    [HotBox-B_Cu.gbl, HotBox-B_Mask.gbs, HotBox-B_Paste.gbp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]
2020-09-13 Added the build folder which contains all files necessary to order the physical parts of the design.
    [HotBox_sides.dxf]
2020-12-31 Committing 2nd REV. Update PCB to fix issues with REV1. Reduce mechanical size.
    [HotBox-B_Cu.gbl, HotBox-B_Mask.gbs, HotBox-B_Paste.gbp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]
2020-12-31 Add missing files
    [#ex.dxf, Gasket.dxf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]
2020-12-31 Add Build folder
    [Gasket.dxf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]
2020-12-31 Remove unneeded files
    [#ex.dxf, busbar.dxf, busbar.scad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]
2020-12-31 Enable pullups on switches. Needed for REV2 HW.
2022-01-25 init commit of REV3 PCB. - adds a fuse - adds reverse polarity protection - moves fan connector so it can clear the fan - changes one NTC to THT so that a flying probe can be used. - add more info in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
    [HotBox-B_Cu.gbl, HotBox-B_Mask.gbs, HotBox-B_Paste.gbp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]

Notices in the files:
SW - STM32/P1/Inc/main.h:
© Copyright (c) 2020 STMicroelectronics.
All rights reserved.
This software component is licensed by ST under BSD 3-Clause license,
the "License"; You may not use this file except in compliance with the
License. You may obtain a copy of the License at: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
